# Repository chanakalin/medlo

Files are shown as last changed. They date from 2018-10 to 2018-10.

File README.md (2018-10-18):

# Medlo

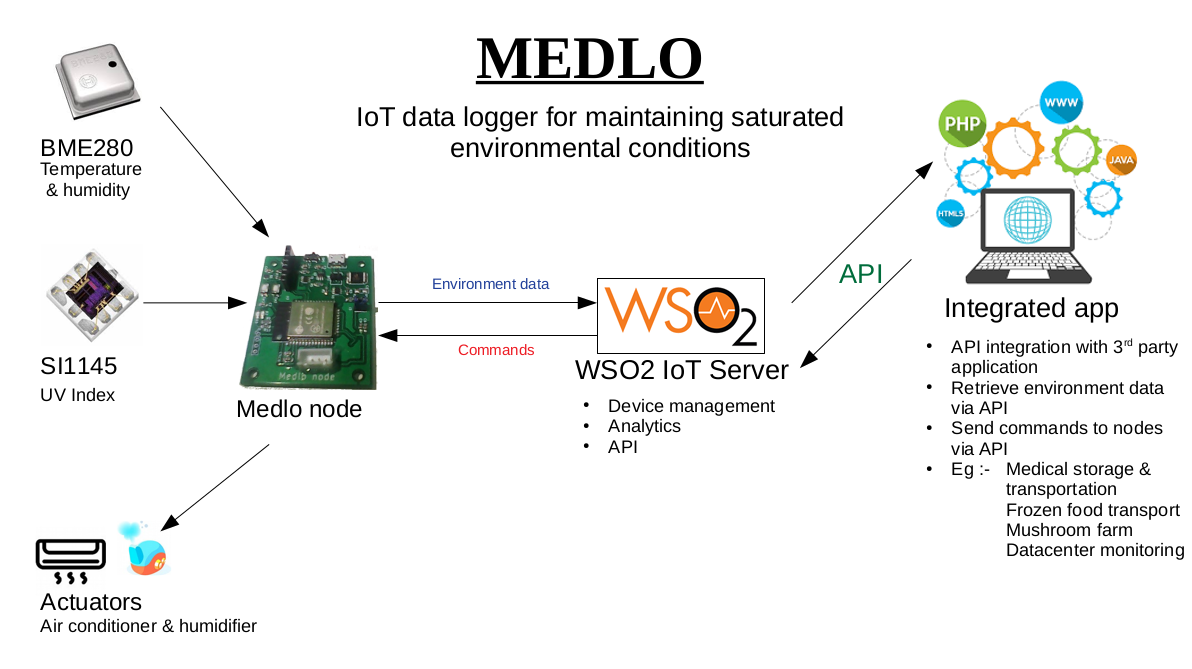
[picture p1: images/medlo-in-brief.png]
Medlo in brief


### Description
Medlo is developed for log environment data and activate pre-programmed actuators. Medlo consists,
* [ESP32] based hardware, Medlo node 
* [WSO2 IoT Server] device type for Medlo node
* API on top of [WSO2 IoT Server]

### Creating device type
Refer Creating a New Device Type via the Maven Archetype on WSO2 library.

### CORS configuration
Refer Enabling CORS for APIs and Enabling CORS for Token APIs in WSO2 APIM by Iloshini Karunarathne for enable CORS

### Sample projects
Two sample projects has been added for reference

[ESP32]: <https://www.espressif.com/en/products/hardware/esp32/overview>
[WSO2 IoT Server]: <https://wso2.com/iot>

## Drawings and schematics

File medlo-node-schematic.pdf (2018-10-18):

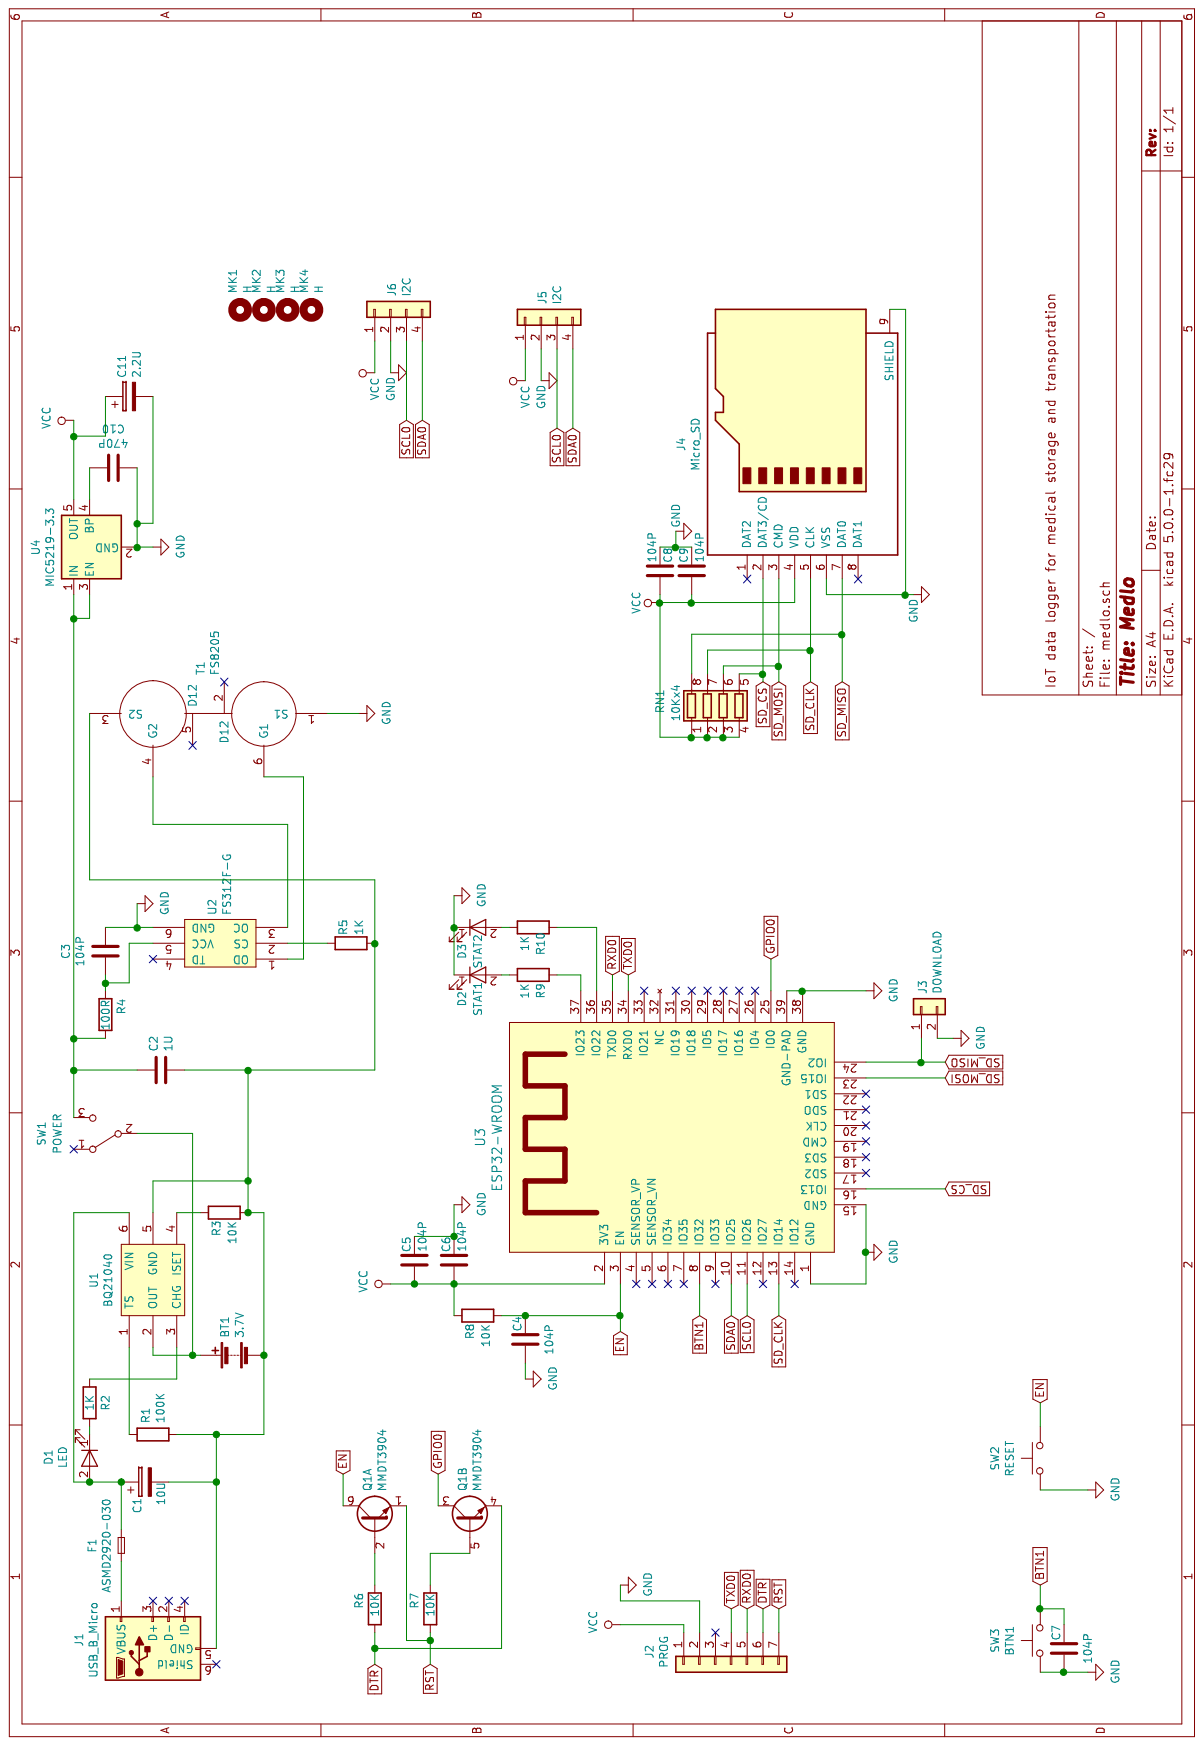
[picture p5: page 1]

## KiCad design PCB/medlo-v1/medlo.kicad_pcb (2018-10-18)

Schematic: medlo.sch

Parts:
BT1: 3.7V; PINHEAD1-2
C1: 10U; CP_Tantalum_Case-R_EIA-2012-12_Hand
C2: 1U; C_0805_HandSoldering
C3, C4, C5, C6, C7, C8, C9: 104P; C_0805_HandSoldering
C10: 470P; C_0805_HandSoldering
C11: 2.2U; CP_Tantalum_Case-A_EIA-3216-18_Hand
D1: LED; LED_0805_HandSoldering
D2: STAT1; LED_0805_HandSoldering
D3: STAT2; LED_0805_HandSoldering
F1: ASMD2920-030; Fuse_SMD2920
J1: USB_B_Micro; USB_Micro-B
J2: PROG; Pin_Header_Straight_1x07_Pitch2.54mm
J3: DOWNLOAD; Pin_Header_Straight_2x01_Pitch2.54mm
J4: Micro_SD; microSD_Card_Receptacle_Wuerth_693072010801
J5, J6: I2C; Pin_Header_Straight_1x04_Pitch2.54mm
MK1, MK2, MK3, MK4: H; MountingHole_3.2mm_M3_ISO14580
Q1: MMDT3904; SOT-363_SC-70-6
R1: 100K; R_0805_HandSoldering
R2, R5, R9, R10: 1K; R_0805_HandSoldering
R3, R6, R7, R8: 10K; R_0805_HandSoldering
R4: 100R; R_0805_HandSoldering
RN1: 10Kx4; R_Array_Convex_4x0603
SW1: POWER; SW_SPDT_PCM12
SW2: RESET; SW_SPST_EVQP2
SW3: BTN1; SW_SPST_EVQP2
T1: FS8205; SOT-23-6_Handsoldering
U1: BQ21040; SOT-23-6_Handsoldering
U2: FS312F-G; SOT-23-6_Handsoldering
U3: ESP32-WROOM
U4: MIC5219-3.3; SOT-23-5

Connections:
BTN1: C7.1, SW3.2, U3.8
DTR: J2.6, Q1.4 (E2), R6.2
EN: C4.1, Q1.6 (C1), R8.2, SW2.2, U3.3
GND: C3.1, C4.2, C5.1, C6.1, C7.2, C8.1, C9.1, C10.1, C11.2, D2.1, D3.1, J2.2, J3.2, J4.6, J4.9, J5.2, J6.2, SW2.1, SW3.1, T1.1, U2.6, U3.1, U3.15, U3.38, U3.39, U4.2 (GND)
GPIO0: Q1.3 (C2), U3.25
unnamed: BT1.1, SW1.2, U1.2
unnamed: BT1.2, C1.2, C2.2, J1.5, R1.2, R3.2, R5.2, T1.3, U1.5
unnamed: C1.1, D1.2, F1.2, U1.6
unnamed: C2.1, R4.2, SW1.3, U4.1 (IN), U4.3 (EN)
unnamed: C3.2, R4.1, U2.5
unnamed: C10.2, U4.4 (BP)
unnamed: D1.1, R2.2
unnamed: D2.2, R9.2
unnamed: D3.2, R10.2
unnamed: F1.1, J1.1
unnamed: Q1.2 (B1), R6.1
unnamed: Q1.5 (B2), R7.1
unnamed: R1.1, U1.1
unnamed: R2.1, U1.3
unnamed: R3.1, U1.4
unnamed: R5.1, U2.2
unnamed: R9.1, U3.37
unnamed: R10.1, U3.36
unnamed: T1.4, U2.3
unnamed: T1.6, U2.1
RST: J2.7, Q1.1 (E1), R7.2
RXD0: J2.5, U3.35
SCL0: J5.3, J6.3, U3.11
SDA0: J5.4, J6.4, U3.10
SD_CLK: J4.5, RN1.7, U3.13
SD_CS: J4.2, RN1.5, U3.16
SD_MISO: J3.1, J4.7, RN1.8, U3.24
SD_MOSI: J4.3, RN1.6, U3.23
TXD0: J2.4, U3.34
VCC: C5.2, C6.2, C8.2, C9.2, C11.1, J2.1, J4.4, J5.1, J6.1, R8.1, RN1.1, RN1.2, RN1.3, RN1.4, U3.2, U4.5 (OUT)

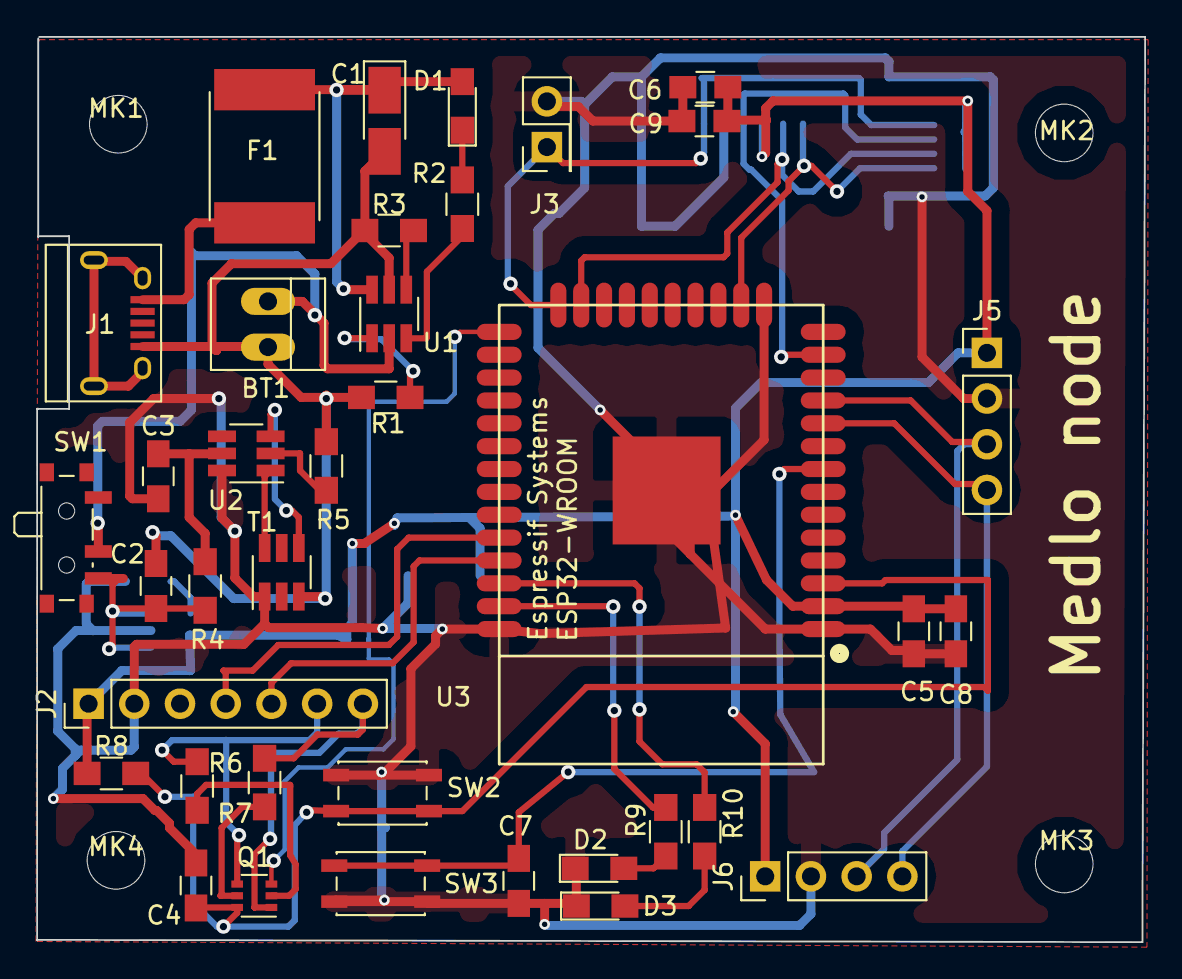
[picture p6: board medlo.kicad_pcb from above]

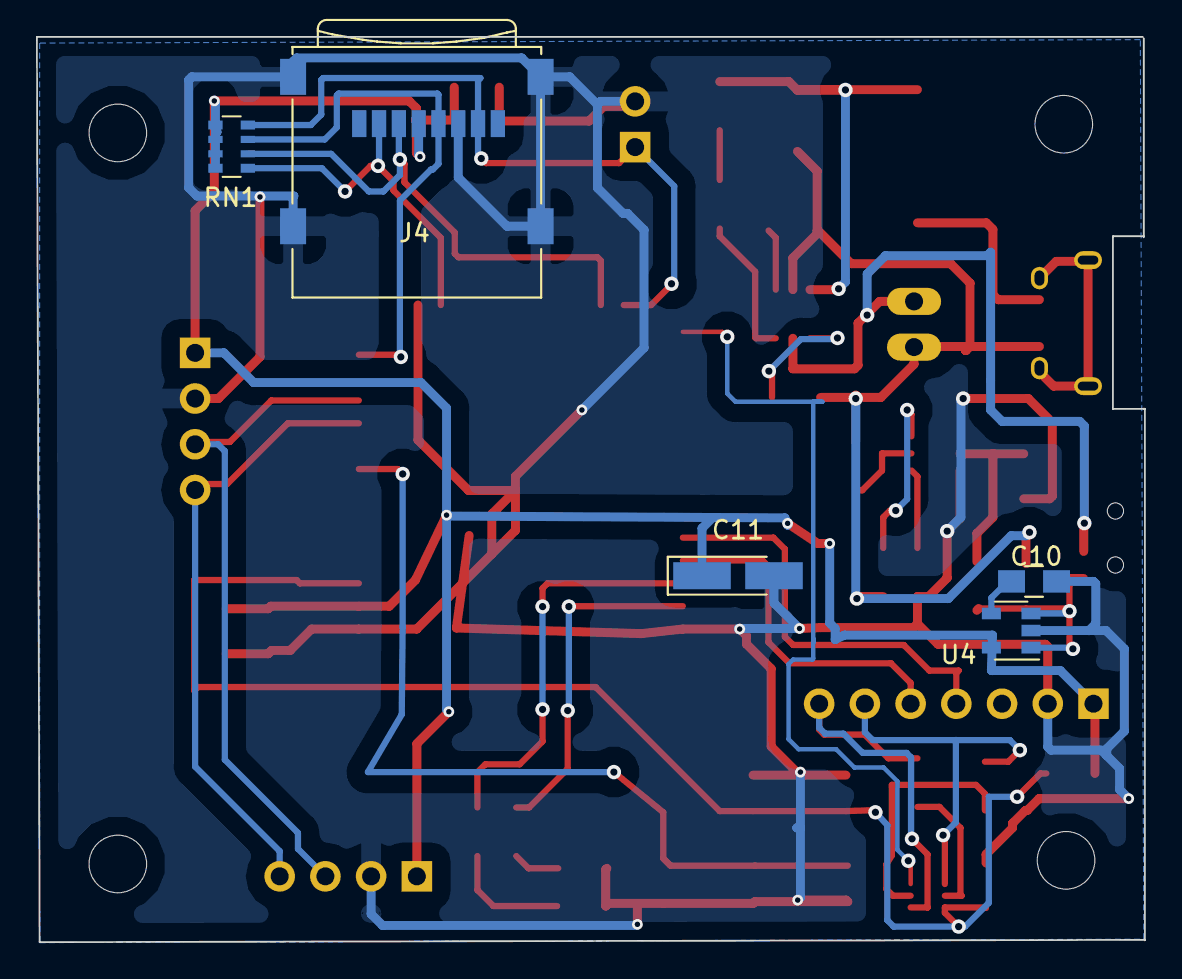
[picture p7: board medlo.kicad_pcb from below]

Board: 2 copper layers, 61.6 x 50.3 mm, 46 parts (5 on the bottom side), 35 nets.

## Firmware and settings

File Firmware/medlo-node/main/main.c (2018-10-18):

/*
 * Medlo node
 */
#include <string.h>

#include <esp_event.h>
#include <esp_event_loop.h>
#include <esp_system.h>
#include <esp_wifi.h>
#include <esp_err.h>
#include <esp_log.h>
#include <freertos/FreeRTOS.h>
#include <lwip/sockets.h>
#include <nvs_flash.h>
#include <sdmmc_cmd.h>
#include "driver/uart.h"
#include "driver/gpio.h"
#include <cJSON.h>
#include <sdkconfig.h>
#include <hwcrypto/sha.h>
#include <mqtt_client.h>
//time & HTTPS
#include "lwip/err.h"
#include "lwip/apps/sntp.h"
#include "lwip/sockets.h"
#include "lwip/sys.h"
#include "lwip/netdb.h"
#include "lwip/dns.h"
#include "esp_tls.h"
#include <esp_http_client.h>
#include <time.h>
#include <sys/time.h>
#include <esp_tls.h>
//medlo
#include "medlo.h"
#include "medlo_mqtt.h"
#include "medlo_time.h"
#include "medlo_payload.h"
#include "medlo_data.h"
#include "medlo_status_led.h"
#include "medlo_storage.h"
#include "token_refresh.h"
//medlo components
#include <medlo-i2c.h>
#include <bme280.h>
#include <medlo_operator.h>
#include <si1145.h>

static esp_err_t wifi_event_handler(void *ctx, system_event_t *event) {
	switch (event->event_id) {
	case SYSTEM_EVENT_STA_START:
		esp_wifi_connect();
		break;
	case SYSTEM_EVENT_STA_GOT_IP:
		ESP_LOGI(MEDLO_TAG, "Connected to WIFI")
		;
		led_green(1);
		led_blue(0);
		ntp_init_time();
		//MQTT
		mqtt_init();
		xTaskCreate(&task_datasend, "task_datasend", 16384, NULL, 5, NULL);
		break;
	case SYSTEM_EVENT_STA_DISCONNECTED:
		//switch to offline mode
		break;
	case SYSTEM_EVENT_STA_WPS_ER_SUCCESS:
		/*point: the function esp_wifi_wps_start() only get ssid & password
		 * so call the function esp_wifi_connect() here
		 * */
		ESP_LOGI(MEDLO_TAG, "SYSTEM_EVENT_STA_WPS_ER_SUCCESS")
		;
		ESP_ERROR_CHECK(esp_wifi_wps_disable())
		;
		ESP_ERROR_CHECK(esp_wifi_connect())
		;
		ESP_LOGI(MEDLO_TAG, "Connected to WIFI using WPS")
		;
		led_green(1);
		led_blue(0);
		ntp_init_time();
		//MQTT
		//mqtt_init();
		break;
	case SYSTEM_EVENT_STA_WPS_ER_FAILED:
		ESP_LOGI(MEDLO_TAG, "SYSTEM_EVENT_STA_WPS_ER_FAILED")
		;
		ESP_ERROR_CHECK(esp_wifi_wps_disable())
		;
		ESP_ERROR_CHECK(esp_wifi_wps_enable(&wps_config))
		;
		ESP_ERROR_CHECK(esp_wifi_wps_start(0))
		;
		break;
	case SYSTEM_EVENT_STA_WPS_ER_TIMEOUT:
		ESP_LOGI(MEDLO_TAG, "SYSTEM_EVENT_STA_WPS_ER_TIMEOUT")
		;
		ESP_ERROR_CHECK(esp_wifi_wps_disable())
		;
		ESP_ERROR_CHECK(esp_wifi_wps_enable(&wps_config))
		;
		ESP_ERROR_CHECK(esp_wifi_wps_start(0))
		;
		break;
	case SYSTEM_EVENT_STA_WPS_ER_PIN:
		ESP_LOGI(MEDLO_TAG, "SYSTEM_EVENT_STA_WPS_ER_PIN")
		;
		/*show the PIN code here*/
		ESP_LOGI(MEDLO_TAG, "WPS_PIN = "PINSTR,
				PIN2STR(event->event_info.sta_er_pin.pin_code))
		;
		break;
	default:
		break;
	}
	return ESP_OK;
}

void app_main() {
	ESP_LOGI(MEDLO_TAG, "[APP] Startup..");
	ESP_LOGI(MEDLO_TAG, "[APP] Free memory: %d bytes", esp_get_free_heap_size());
	ESP_LOGI(MEDLO_TAG, "[APP] IDF version: %s", esp_get_idf_version());
	medlo_nvs_init();
	tcpip_adapter_init();
	medlo_gpio_init();

	medlo_spiffs_init();
	medlo_spiffs_read_tokens();
	ESP_LOGI(MEDLO_TAG,"Auth token=%s\nRefresh token=%s\n\n",authtoken,refreshtoken);


	ESP_ERROR_CHECK(esp_event_loop_init(wifi_event_handler, NULL));
	 wifi_init_config_t cfg = WIFI_INIT_CONFIG_DEFAULT()
	 ;
	 ESP_ERROR_CHECK(esp_wifi_init(&cfg));
	 ESP_ERROR_CHECK(esp_wifi_set_storage(WIFI_STORAGE_RAM));
	 ESP_ERROR_CHECK(esp_wifi_set_mode(WIFI_MODE_STA));

	 //WPS
	 if (wps_switch_status()) {
	 led_green(1);
	 led_blue(1);
	 ESP_ERROR_CHECK(esp_wifi_start());
	 ESP_LOGI(MEDLO_TAG, "start wps...");
	 ESP_ERROR_CHECK(esp_wifi_wps_enable(&wps_config));
	 ESP_ERROR_CHECK(esp_wifi_wps_start(0));
	 } else { //ssid and passwd
	 led_green(0);
	 led_blue(1);
	 wifi_config_t wifi_config = { .sta = { .ssid = WIFI_SSID, .password =
	 WIFI_PASSWORD, }, };
	 ESP_ERROR_CHECK(esp_wifi_set_config(ESP_IF_WIFI_STA, &wifi_config));
	 ESP_LOGI(MEDLO_TAG, "start the WIFI SSID:[%s]", WIFI_SSID);
	 ESP_ERROR_CHECK(esp_wifi_start());
	 ESP_LOGI(MEDLO_TAG, "Waiting for wifi");
	 }

}

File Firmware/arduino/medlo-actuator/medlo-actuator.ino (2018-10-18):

#include <Wire.h>

#define LED_R 2
#define LED_G 3
#define LED_B 4

void setup() {
  pinMode(LED_R, OUTPUT);
  pinMode(LED_G, OUTPUT);
  pinMode(LED_B, OUTPUT);
  Wire.begin(8);                // join i2c bus with address #10
  Wire.onReceive(receiveEvent); // register event
}

void loop() {
  delay(100);
}

void receiveEvent(int howMany) {
  char c = 'a';
  c = Wire.read(); 
  

  if(c=='R'){
    digitalWrite(LED_R,HIGH);
  }
  if(c=='r'){
    digitalWrite(LED_R,LOW);
  }
  if(c=='G'){
    digitalWrite(LED_G,HIGH);
  }
  if(c=='g'){
    digitalWrite(LED_G,LOW);
  }
  if(c=='B'){
    digitalWrite(LED_B,HIGH);
  }
  if(c=='b'){
    digitalWrite(LED_B,LOW);
  }

}
